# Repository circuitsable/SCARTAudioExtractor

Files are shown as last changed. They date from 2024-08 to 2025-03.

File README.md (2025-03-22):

# SCARTAudioExtractor
This is a PCB that acts as a SCART female-to-female coupler/gender changer, but extracts the audio from the input to a 3.5mm TRS jack (EuroSCART only).

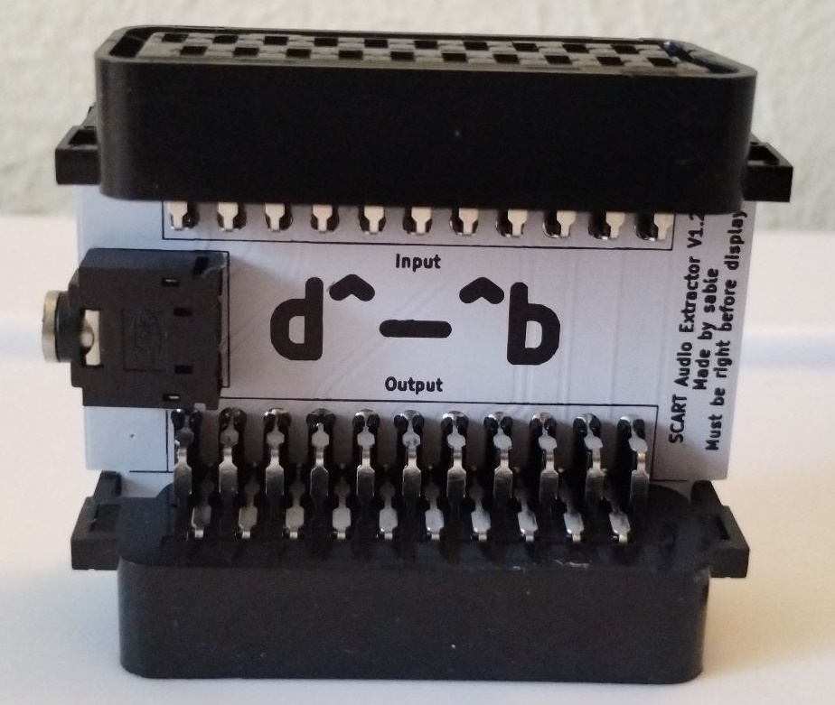
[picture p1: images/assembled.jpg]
Assembled board


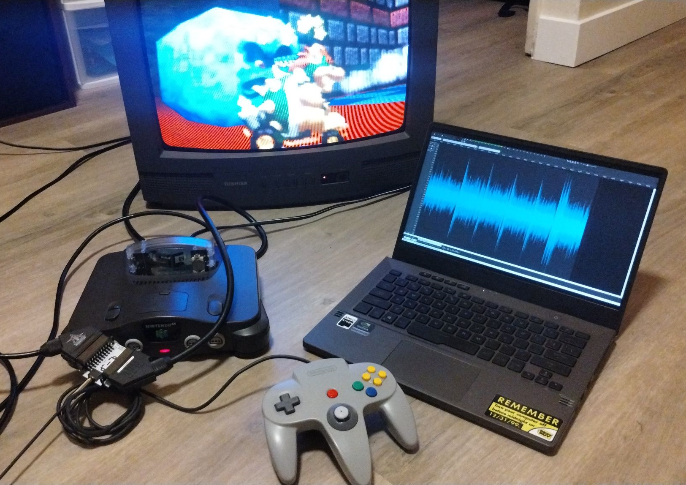
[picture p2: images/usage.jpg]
Board in use


# Why/About

I have several older game consoles that output their video and audio over SCART, and I often want to listen to the game audio with headphones.

I designed this board because the few products that extract audio from a SCART cable either terminate to RCA jacks, are out of stock, or do not support RGB.

This board must be right before your display! Audio is completely removed from the SCART cable, and you will not get audio from the output SCART connector. This coupler also does not support daisy chaining and removes the mostly unused D2B bus signals as well.

Create an issue if you would like a version that uses RCA jacks or JP-21.

# What you'll need

The PCB, of which gerbers are available for in the [releases](https://github.com/circuitsable/SCARTAudioExtractor/releases/tag/gerbers). The PCB can be ordered from any board house, some examples of which are [Oshpark](https://oshpark.com/#services), [PCBWay](https://www.pcbway.com/QuickOrderOnline.aspx) or [JLCPCB](https://cart.jlcpcb.com/quote). Included in the releases are two versions, for PCBWay and JLCPCB respectively, which each have the board house's order number markers in the apropriate place.

2 Female SCART Connectors (specifically, [KYCON_SCART_K-SCARTX-022_Horizontal](https://www.mouser.com/datasheet/2/222/K-SCARTX-022-183347.pdf)). No major suppliers carry SCART connectors anymore as far as I'm aware, you can find listings on Aliexpress [here (LR Ear)](https://www.aliexpress.us/item/3256803860252051.html), [here (VER3)](https://www.aliexpress.us/item/2255800585241541.html) or [here (03)](https://www.aliexpress.us/item/3256806450160956.html). Ensure that the part that juts out is on the top (opposite side of the pins), the connector has ears, is a horizontal/90 degree connector, has all 21 pins (to ensure RGB support), and does not have any extra mounting methods besides the ears (e.g, screw holes).

1 Female 3.5mm TRS Jack (specifically, [Jack_3.5mm_CUI_SJ1-3523N_Horizontal](https://www.cuidevices.com/product/resource/pdf/sj1-352xn.pdf)). This can be bought from [Mouser](https://www.mouser.com/ProductDetail/CUI-Devices/SJ1-3523N?qs=WyjlAZoYn50aNl0vAhb3Tg%3D%3D), [Digikey](https://www.digikey.com/en/products/detail/cui-devices/SJ1-3523N/738689) or Aliexpress [here](https://www.aliexpress.us/item/2251832685563184.html), [here](https://www.aliexpress.us/item/3256803939752840.html) or [here](https://www.aliexpress.us/item/3256805272161608.html).

Basic soldering equipment.

(Optional) Rubber feet or a case of some sort

# PCB Images

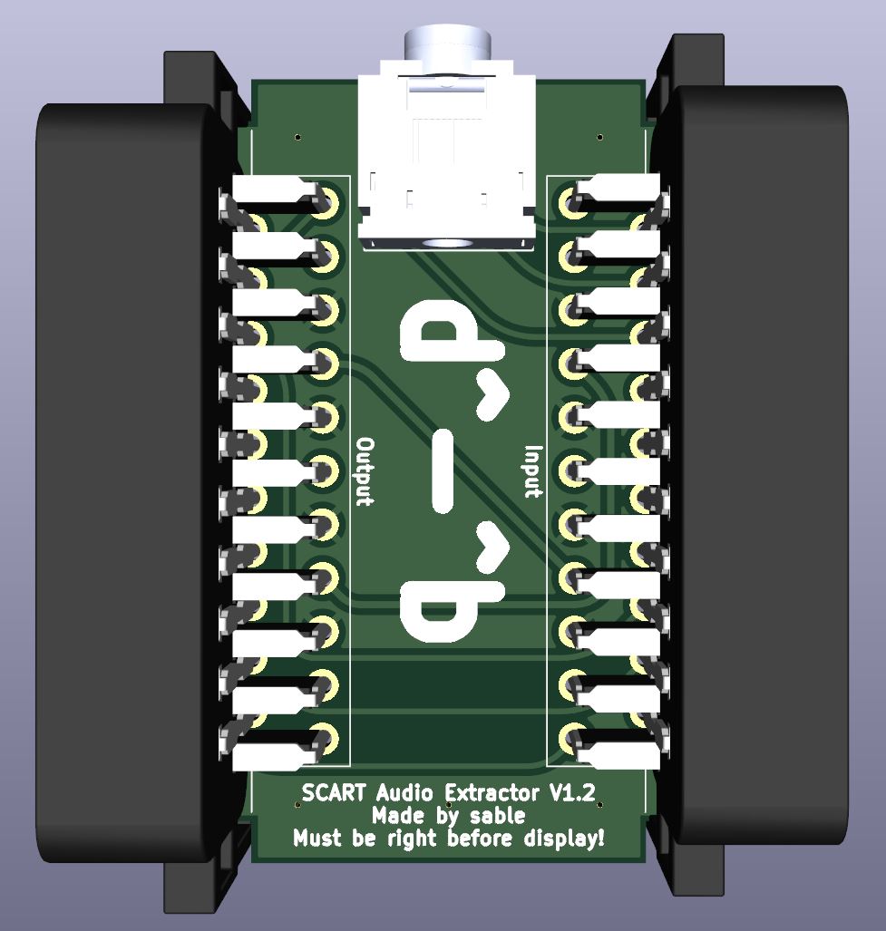
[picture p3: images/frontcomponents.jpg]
PCB Front w/ Components


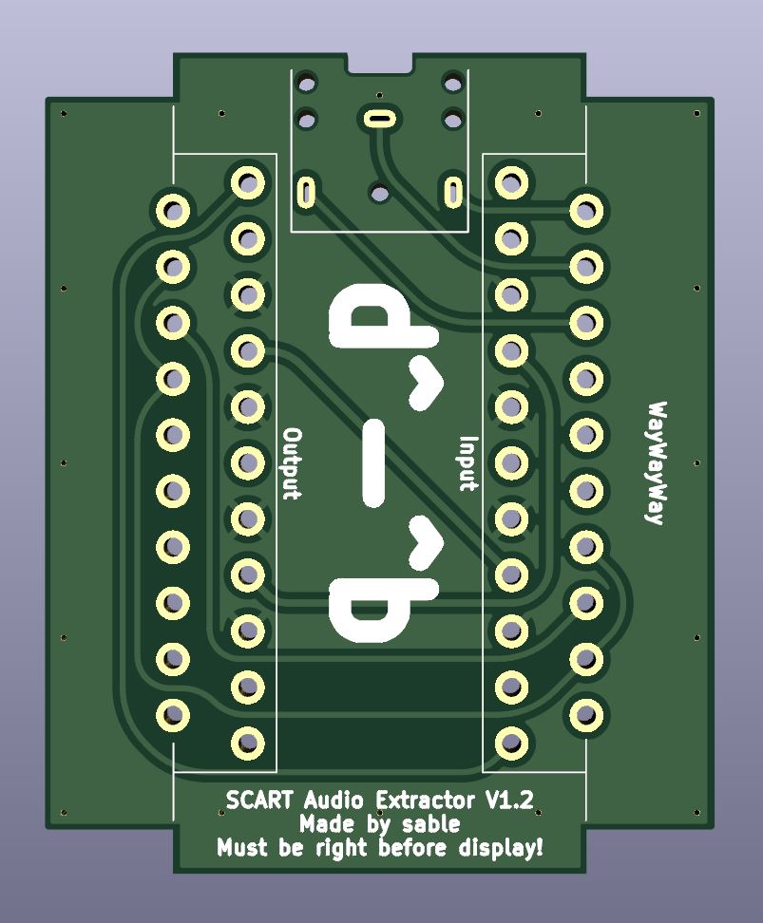
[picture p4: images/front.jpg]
PCB Front w/o Components


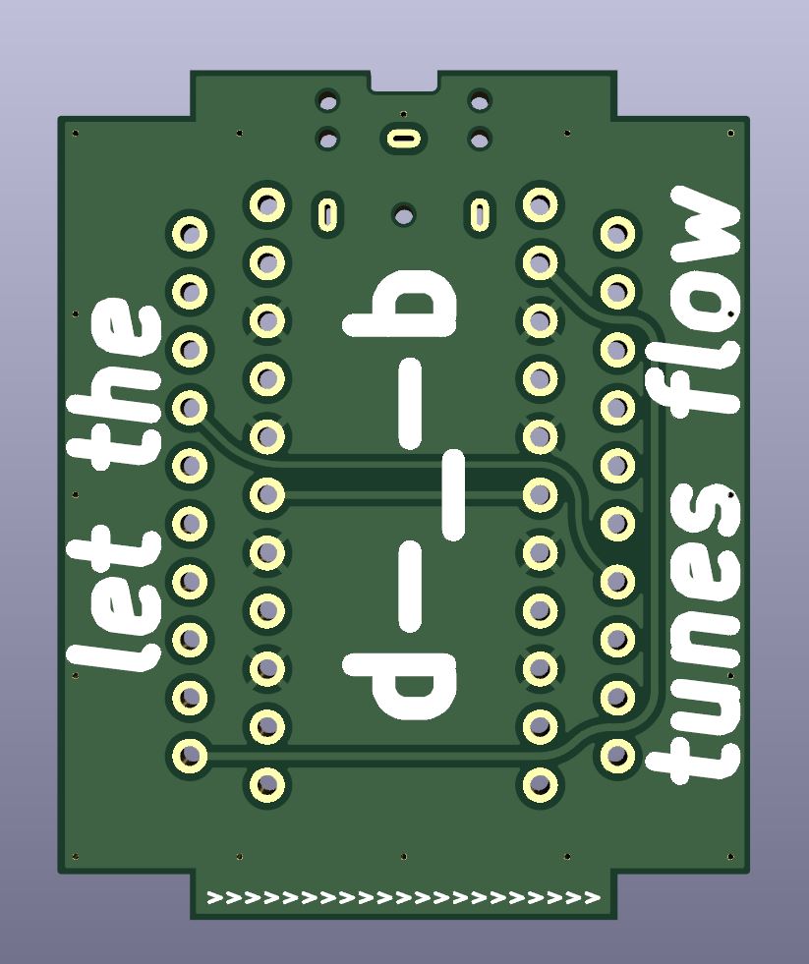
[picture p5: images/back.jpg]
PCB Back


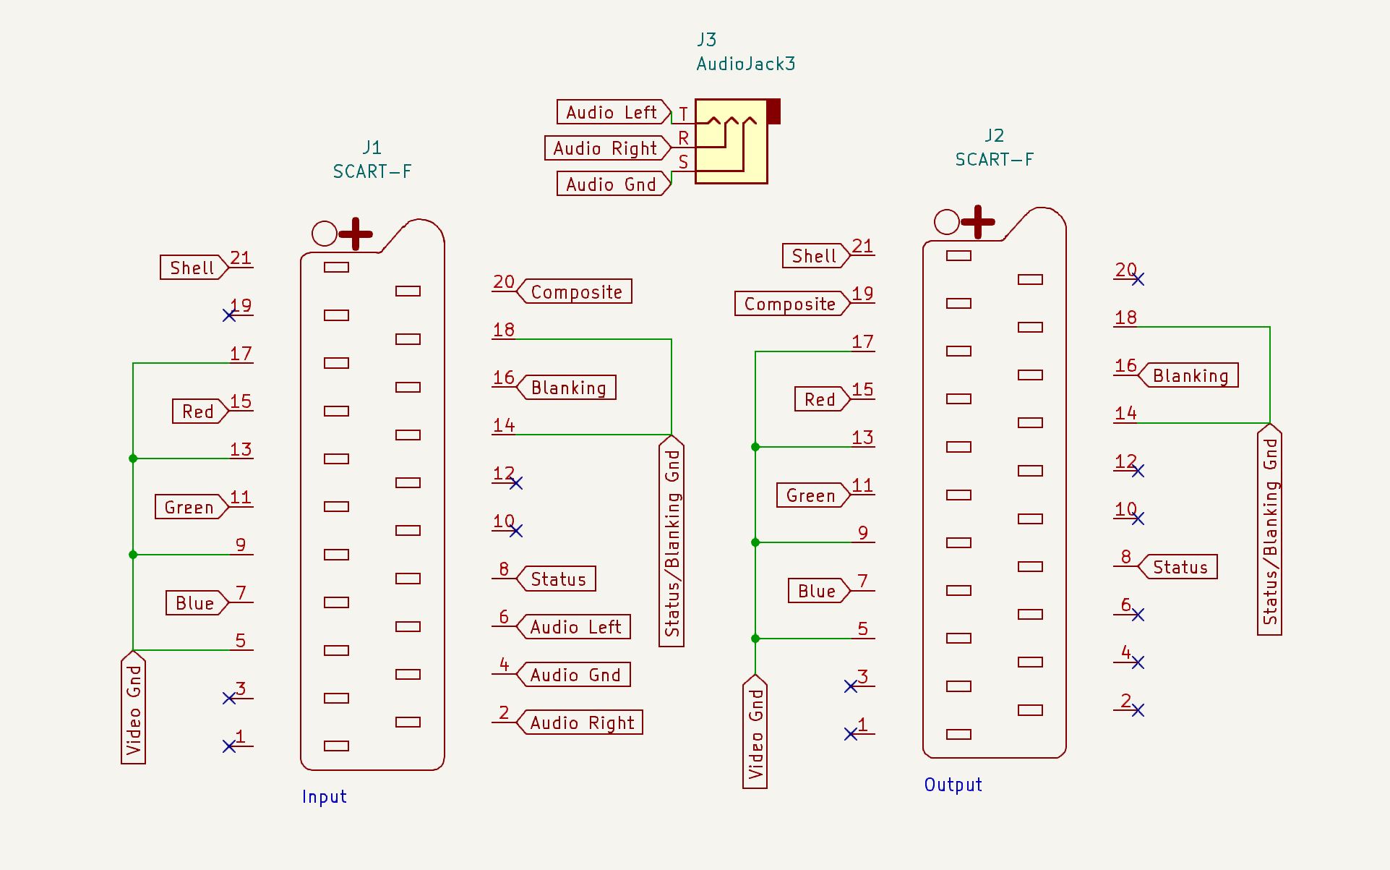
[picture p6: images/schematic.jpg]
Schematic


# TODO

Design a 3D printable shell to protect against shorts/damage to the board.

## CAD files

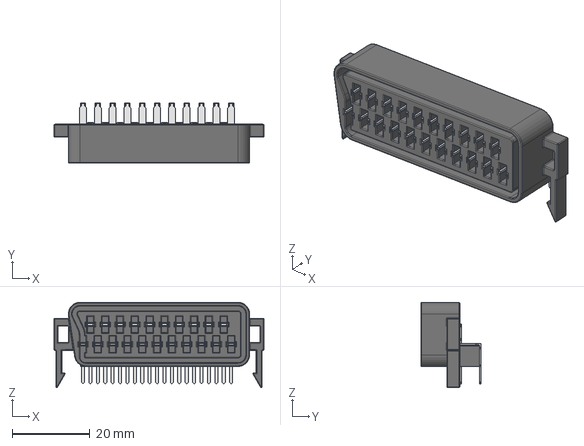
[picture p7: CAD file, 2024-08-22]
kicad project/KYCON_SCART_K-SCARTX-022_Horizontal.step
54.0 x 15.5 x 22.0 mm

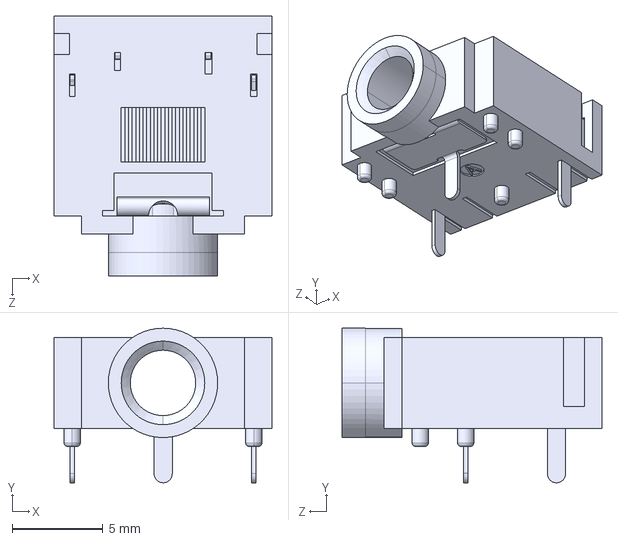
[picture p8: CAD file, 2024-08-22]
kicad project/Jack_3.5mm_CUI_SJ1-3523N_Horizontal.step
12.0 x 8.51 x 14.3 mm

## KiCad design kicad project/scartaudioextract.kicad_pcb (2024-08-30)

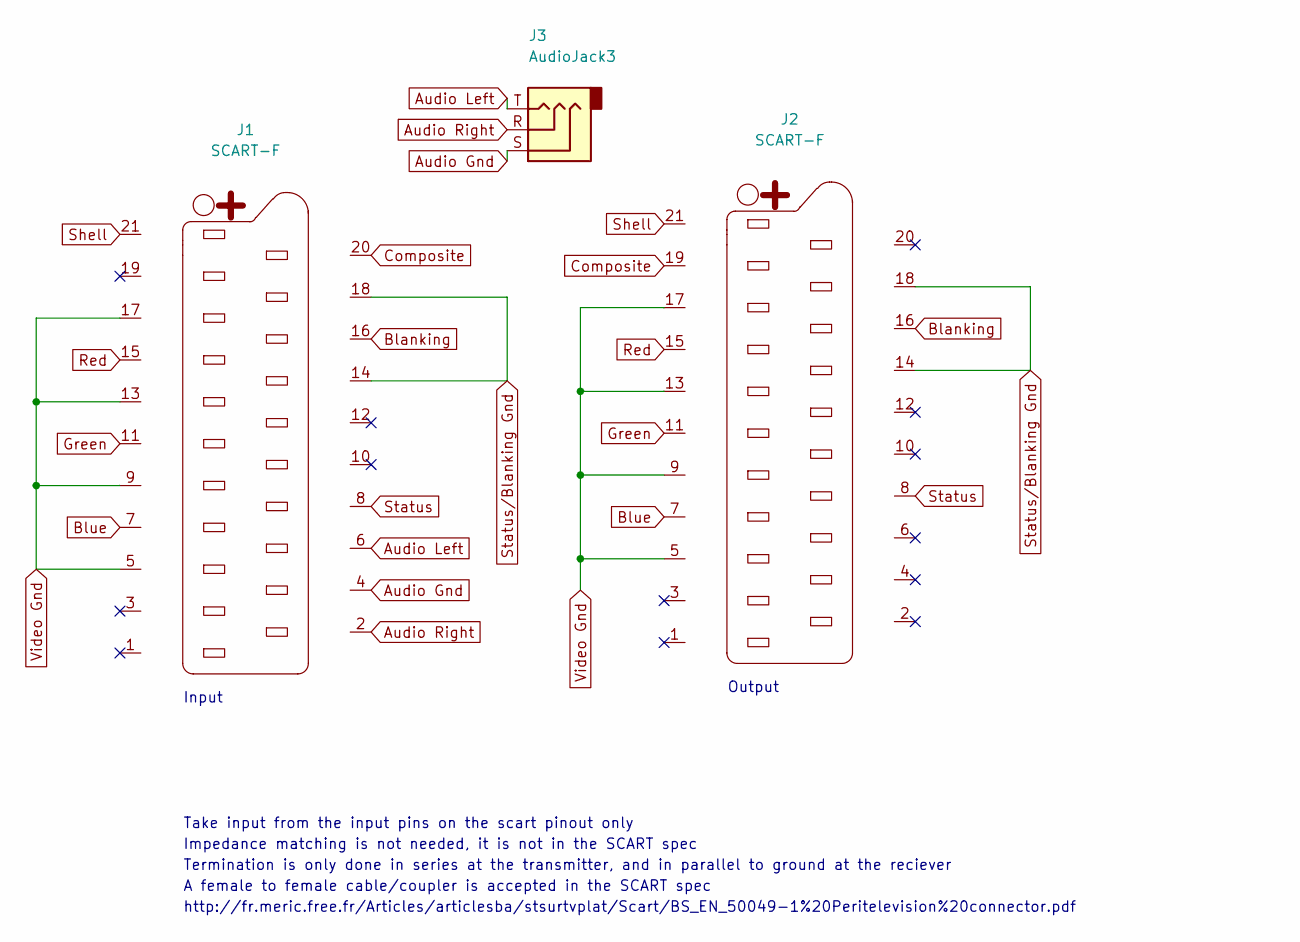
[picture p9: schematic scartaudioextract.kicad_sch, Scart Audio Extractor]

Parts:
J1, J2: SCART-F; KYCON_SCART_K-SCARTX-022_Horizontal
J3: AudioJack3; Jack_3.5mm_CUI_SJ1-3523N_Horizontal

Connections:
Audio Gnd: J1.4, J3.S
Audio Left: J1.6, J3.T
Audio Right: J1.2, J3.R
Blanking: J1.16, J2.16
Blue: J1.7, J2.7
Composite: J1.20, J2.19
Green: J1.11, J2.11
Red: J1.15, J2.15
Shell: J1.21, J2.21
Status: J1.8, J2.8
Status/Blanking Gnd: J1.14, J1.18, J2.14, J2.18
Video Gnd: J1.5, J1.9, J1.13, J1.17, J2.5, J2.9, J2.13, J2.17

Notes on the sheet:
Take input from the input pins on the scart pinout only
Termination is only done in series at the transmitter, and in parallel to ground at the reciever
Input
Output
http://fr.meric.free.fr/Articles/articlesba/stsurtvplat/Scart/BS_EN_50049-1%20Peritelevision%20connector.pdf
Impedance matching is not needed, it is not in the SCART spec
A female to female cable/coupler is accepted in the SCART spec

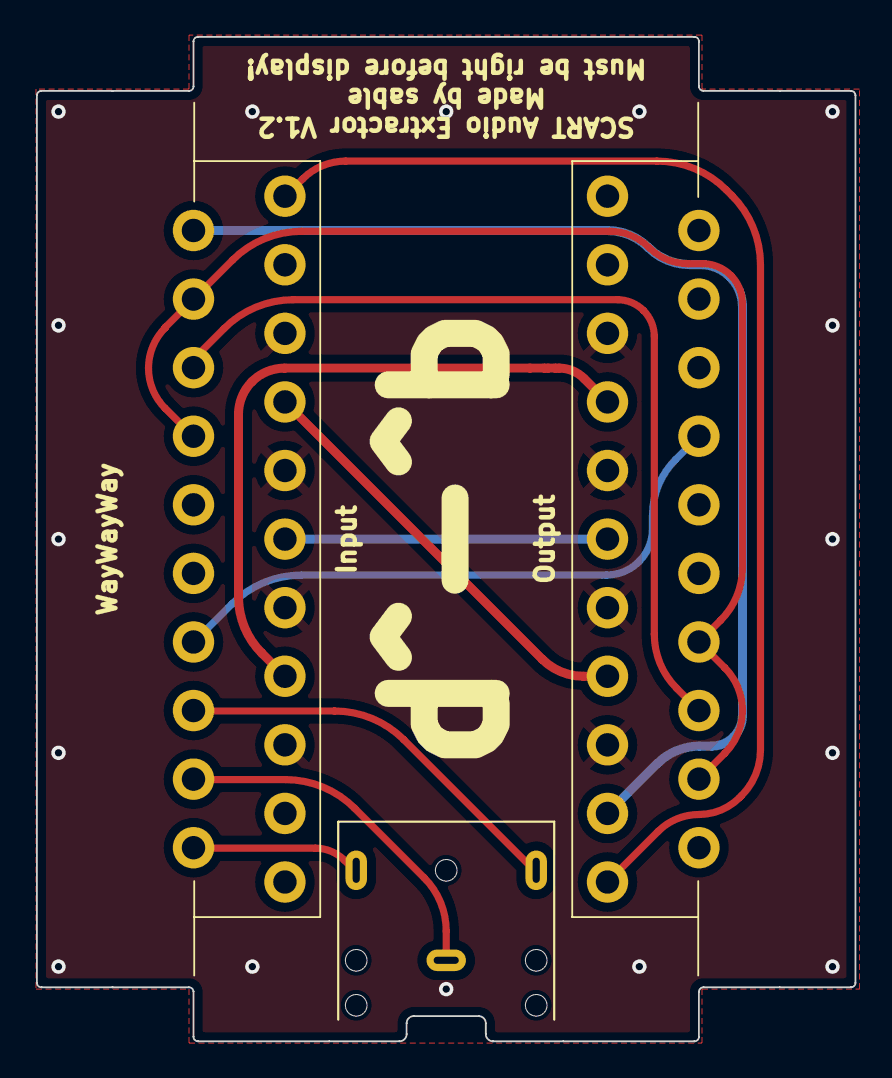
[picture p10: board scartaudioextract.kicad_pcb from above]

Board: 2 copper layers, 45.5 x 55.8 mm, 3 parts (0 on the bottom side), 12 nets.

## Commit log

2024-08-22 Add gerbers
    [scartaudioextract-B_Cu.gbr, scartaudioextract-B_Mask.gbr, scartaudioextract-B_Paste.gbr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]
2024-08-22 Add KiCad Project
    [Jack_3.5mm_CUI_SJ1-3523N_Horizontal.step, KYCON_SCART_K-SCARTX-022_Horizontal.step, scartaudioextract.kicad_pcb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]
2024-08-24 add termination resistors
2024-08-24 add schematic
2024-08-25 remove termination resistors
2024-08-25 forgot a connection
    [scartaudioextract-B_Cu.gbr, scartaudioextract-B_Mask.gbr, scartaudioextract-B_Paste.gbr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]
2024-08-25 add extra info
    [scartaudioextract.kicad_sch]
2024-08-30 improve schematic, use better design rules
    [scartaudioextract.kicad_pcb, scartaudioextract.kicad_sch]
2024-08-30 new gerbers
    [scartaudioextract-B_Cu.gbr, scartaudioextract-B_Mask.gbr, scartaudioextract-B_Paste.gbr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]
2024-10-10 add assembled board image
2026-09-01 Add JP21 to Euro Extract
    Solves Issue 1 (https://github.com/circuitsable/SCARTAudioExtractor/issues/1)
